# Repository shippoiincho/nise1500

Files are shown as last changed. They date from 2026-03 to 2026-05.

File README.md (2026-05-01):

# 偽 1500 for MZ-700

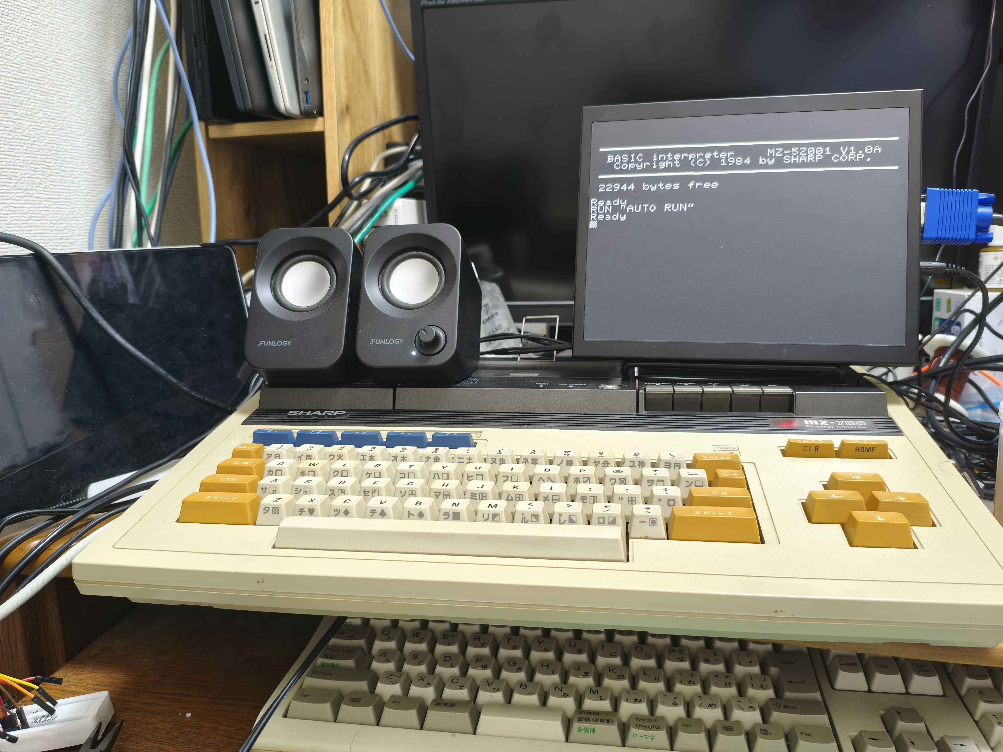
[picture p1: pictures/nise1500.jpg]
nise1500


## これはなに？

MZ-700 を MZ-1500 もどきにします。
本体の拡張コネクタに装着します。
映像は VGA コネクタから、音声は 3.5mm Jack から出力されます。
QuickDisk は読み込み専用でサポートされています。

偽 RAMFILE の以下の機能もありますが、フラシュサイズの関係で一部容量が削減されています。

- MZ-1R18 RAMFILE
- MZ-1R23 漢字 ROM
- MZ-1R24 辞書 ROM
- MZ-1R12 SRAM メモリ
- PIO-3034 EMM
- PCG-700

---
## 回路

board

Z80 Bus に直結するために、
ピンの多い RP2350B のボード(WeAct RP2350B Core Board)を使用します。
カートリッジスロットの信号を、単純に Raspberry Pi Pico2 に接続しただけです。
Pico2 が 5V 耐性なのを良いことに直結しています。

```
GP0-7:  D0-7
GP8-23: A0-15
GP24: EXINT
GP25: RESET
GP26: M1
GP28: MERQ
GP29: IORQ
GP30: WR
GP31: RD
GP32: EXWAIT
VBUS: 5V
GND: GND
```

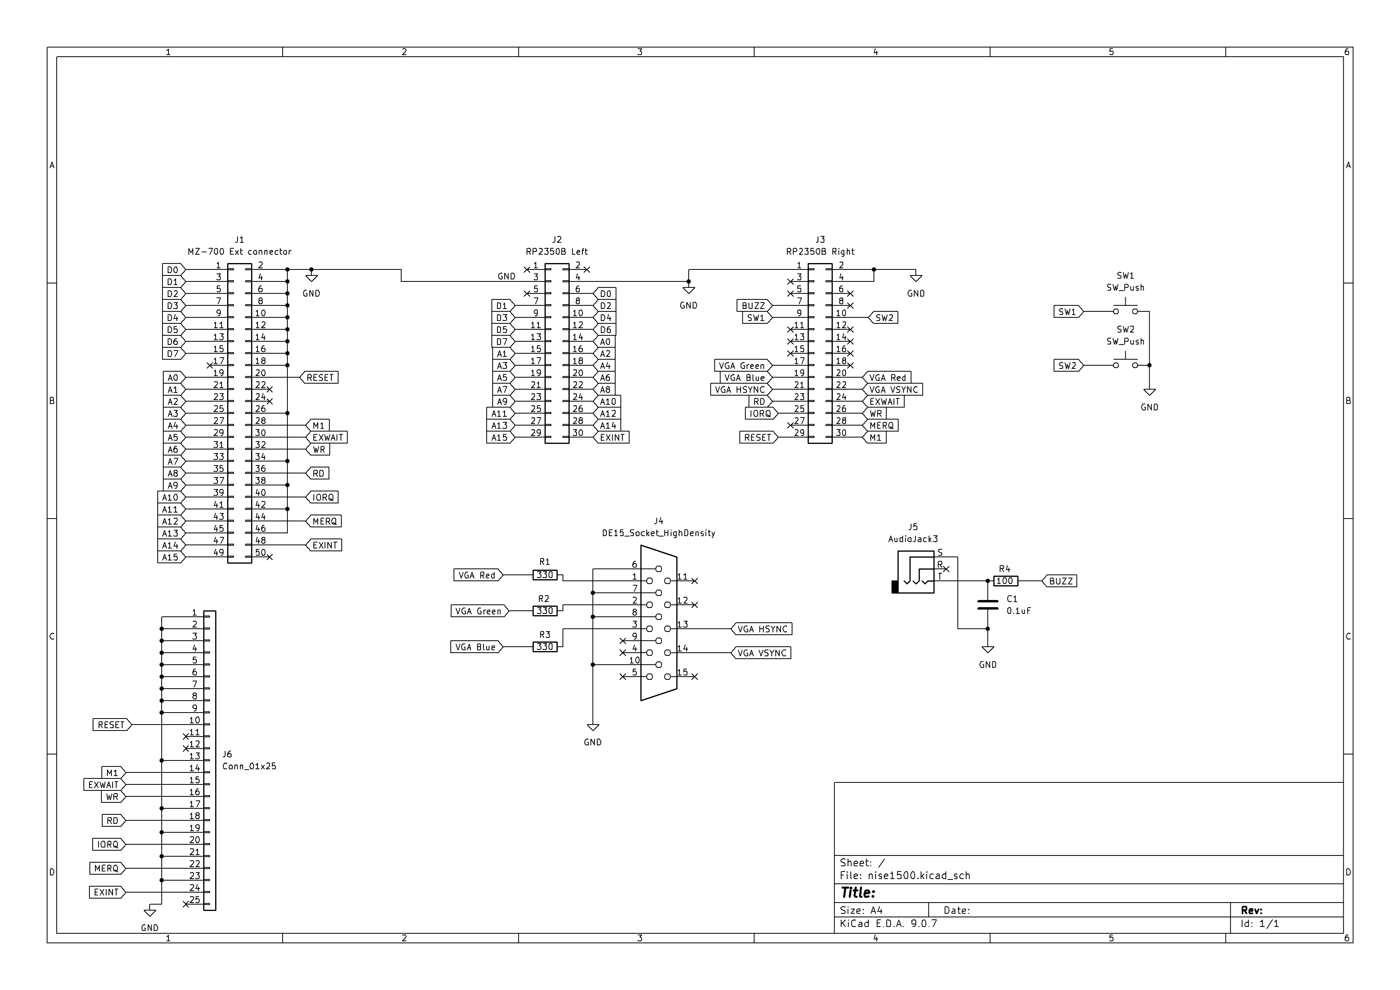
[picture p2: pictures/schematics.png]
Schematics


付属の基板データ `GERBER-nise1500.zip` を用いた場合、MZ-700 の背面コネクタに直結する形を想定しています。
延長ケーブルを使う際はコネクタの装着方向に注意してください。
3.5mm Jack は[ST-005-G](https://akizukidenshi.com/catalog/g/g102460/)を使っています。

MZ-700 の拡張コネクタには電源が出ていません。
別途 Pico の USB 端子などに電源を接続する必要があります。

---
## バイナリとか

`nise1500.uf2` をフラッシュに書き込んでください。
PCG書き込み時にウェイトが入るように調整していますが、環境によってはただしく動作しないことがあります。
BASIC 上で `CLS 2` を実行して正しく画面消去されるかどうか確認してください。

```
INIT "CRT:G"
PAINT [7]0,0
CLS 2
```

これで画面にゴミが残るようであれば、PCG ウェイトが正しく動作していません。

ソース上の `#define PCGWAIT` をコメントアウトすると PCG 書き込みのウェイトがなくなり安定動作しますが、
ソフトによっては速度が速すぎて不具合が生じることがあります。
`nise1500_nopcgwait.uf2` はウェイトオフで作成していますので、こちらを書き込んでください。

---
## 拡張ROM

MZ-1500 の拡張 ROM が必要です。実機から入手してください。

```
picotool.exe load -v -x ext.rom  -t bin -o 0x1001d000
```

---
## QD

QD のイメージ(QDF) ファイルは LittleFS 上に配置します。
LittleFS 領域は 8MiB なので、以下のように作成します。

```
mklittlefs -b 4096 -s 8388608 -c ./nise1500 nise1500.img
```

作った LittleFS イメージを Pico の Flash に書き込みます。

```
picotool.exe load -v -x nise1500.img -t bin -o 0x10800000
```

なお、QuickDisk は読み込み専用です。書き込みはできません。

LittleFS の取り扱いについては、詳しくは[こちらの記事](https://shippoiincho.github.io/posts/39/)を見てください。

QD ファイルの選択は SW1/SW2 を使います。
VGA 画面の一番下(26行目)に選択したファイル名が一定時間表示されます。

---
## MZ-1R18 RAMFILE

64KB の RAM FILE のエミュレーションをします。
BASIC から INIT "RAM:" などで使用することができます。

---
## MZ-1R23 漢字ROM

漢字ROM のエミュレートをします。
あらかじめ picotool などで漢字 ROM のデータを書き込んでおく必要があります。

```
picotool.exe load -v -x kanji.rom  -t bin -o 0x10020000
```

---
## MZ-1R24 辞書ROM

同じく辞書ROM のエミュレートをします。
あらかじめ picotool などで辞書 ROM のデータを書き込んでおく必要があります。

```
picotool.exe load -v -x dict.rom  -t bin -o 0x10040000
```

---
## MZ-1R12 SRAM メモリ

32KB の SRAM メモリのエミュレーションをします。
電源投入時は Checksum Error で止まるようにしています。

フラッシュとのやり取りは、I/O ポートの $BA,$BB を通して行えます。
内部的には 0-63 のバックアップスロットがあって、リード・ライトを制御できます。

$BA に出力するとその番号のスロットから SRAM に読み込みます。

```
OUT@ $BA,1
```

このあとリセットすると、SRAM から起動できます。

$BB に出力すると、SRAM の内容をその番号のスロットに書き込みます。

```
OUT@ $BB,2
```

なお、書き込み中は VGA 出力が停止します。

スロットに書き込みを行っていないデータは電源を切ると消滅します。

基本的な使い方は、モニタの ES コマンドでテープのソフトを SRAM に保存したのち、BASIC 上で上記コマンドで書き込みを行うことになるでしょう。

なお、エミュレータなどで作成したデータを記録することもできます。
アドレス 0x10080000 から 32KiB 単位でおいてください。
最初(0番)のデータは以下のように書き込みます。

```
picotool.exe load -v -x MZboot.rom  -t bin -o 0x10080000
```

起動できるデータの作成を PC 上でするには、
yanataka60さんの[MZ-1500SD 付属のツール 1Z-1R12_Header](https://github.com/yanataka60/MZ-1500_SD)
を使用すると便利です。

---
## PIO-3034 EMM

320KB の EMM をエミュレートします。
Hu-BASIC などで使用することができます。

こちらも I/O ポートの $BC,$BD で読み書きの制御が可能です。
偽 RAMFILE と違ってスロットは 0 - 15 しかありません。

$BC にスロット番号を出力すると EMM に読み込みます。
HuBASIC では以下のように操作します。

```
OUT &HBC,1
```

$BD にスロット番号を出力すると、EMM の内容をフラッシュに書き込みます。

```
OUT &HBD,2
```

なお、書き込み中は VGA 出力が停止します。

フラッシュに書き込みを行っていないデータは電源を切ると消滅します。

---
## PCG-700

VGA 出力に PCG-700 のエミュレーションをします。
本体出力との同期をとっていませんので、ソフトウェアによっては正しく描画されないことがあります。

本来 PCG-700 は、バンク切り替えに関係なく反応しますが、
MZ-1500 用ソフトの動作に支障があるために、VRAM 選択時にのみ動作します。

なお、あらかじめ本体の CG-ROM の内容をフラッシュに書き込んでおく必要があります。

```
picotool.exe load -v -x font.rom  -t bin -o 0x1001f000
```

---
## 制限事項

- ~~MZ-700 に存在しない PCG-RAM のアクセス時にウェイトが入りません。いくつかのソフトで MZ-1500 実機より早くなります~~
- QD は読み込み専用です
- ソフトによっては本体のスピーカーからノイズが発生します。本体のスピーカーの音量調節で対応してください。
- SRAM および EMM データを Flash に書き込む際には VGA 出力が乱れます
- **Flash 書き込み時に QuickDisk、漢字 ROM および辞書 ROM にアクセスすると、ボードの機能が停止します。絶対に行わないでください。**

---
## 使用ライブラリなど

- [LittleFS](https://github.com/littlefs-project/littlefs)
- [VGA ライブラリ(一部改変)](https://github.com/vha3/Hunter-Adams-RP2040-Demos/tree/master/VGA_Graphics)

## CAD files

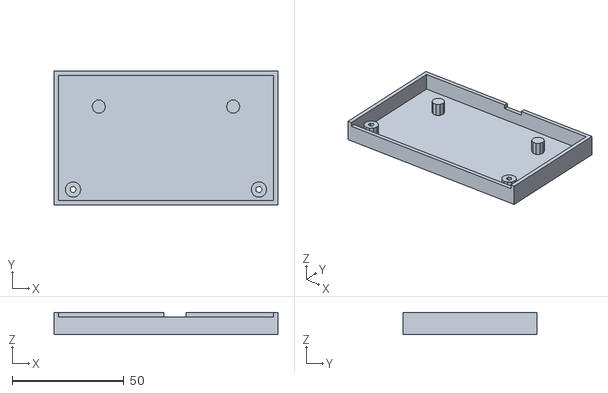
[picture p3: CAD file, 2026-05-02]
case/nise1500case_bottom.stl
100.0 x 60.0 x 10.0

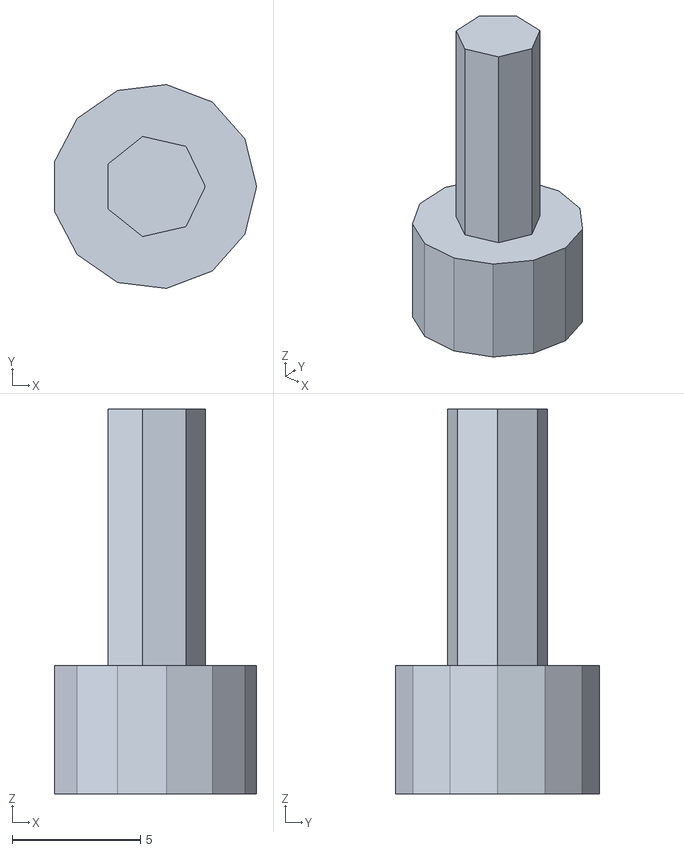
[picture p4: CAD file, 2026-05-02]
case/nise1500case_button.stl
7.88 x 7.94 x 15.0

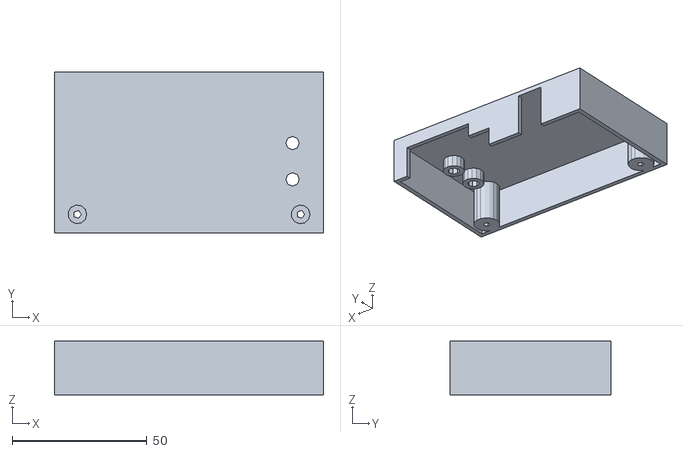
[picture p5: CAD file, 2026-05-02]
case/nise1500case_upper.stl
100.0 x 60.0 x 20.0

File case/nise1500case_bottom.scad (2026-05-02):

// Bottom Outer

difference() {

translate([-50,-30,-10]) {    
cube([100,60,10]);
}


translate([-48,-28,-8]) {  
cube([96,56,8]);
}

translate([-48,-30,-2]) {       
cube([96,56,2]);
    
}

// LINE OUT

translate([-1,25,-2]) {

cube([10,6,2]);

}


translate([-41.5,-23,-10]) {
    
cylinder(6,1.5,1.5);

}

translate([+41.5,-23,-10]) {
        
cylinder(6,1.5,1.5);

}

}


// Bottom Hole 1

translate([-41.5,-23,-8]) {

difference() {
    
cylinder(6,3.5,3.5);    
    
cylinder(6,1.5,1.5);

}
   
}

// Botom Hole 2

translate([+41.5,-23,-8]) {

difference() {
    
cylinder(6,3.5,3.5);    
    
cylinder(6,1.5,1.5);

}
   
}

// Support

translate([-30,14,-8]) {
    

cylinder(6,3,3);

}

translate([30,14,-8]) {
    

cylinder(6,3,3);

}

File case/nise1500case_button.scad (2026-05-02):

cylinder(15,2,2);
cylinder(5,4,4);

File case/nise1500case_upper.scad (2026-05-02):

// Bottom Outer

difference() {

translate([-50,-30,0]) {    
cube([100,60,20]);
}


translate([-48,-28,0]) {  
cube([96,56,18]);
}

translate([-48,-30,-2]) {       
cube([96,56,2]);
    
}

// VGA

translate([10,25,0]) {

cube([33,10,14]);

}

// LINE OUT

translate([-1,25,0]) {

cube([18,6,8]);

}

// USB 

translate([-29,25,0]) {

cube([12,10,18]);

}

// Button Hole

translate([38.5,3.5,18]) {

cylinder(2,2.5,2.5); 

}

translate([38.5,-10,18]) {

cylinder(2,2.5,2.5); 

}


// Mount Hole

translate([-41.5,-23,18]) {
    
cylinder(2,3.5,3.5);    
       
}

translate([41.5,-23,18]) {
    
cylinder(2,3.5,3.5);    
       
}


}


// Upper Hole 1

translate([-41.5,-23,0]) {

difference() {
    
cylinder(4,3.5,3.5);    
    
cylinder(4,1.5,1.5);

}
   
}

translate([-41.5,-23,0]) {

difference() {
    
cylinder(18,5.5,5.5);    
    
cylinder(18,3.5,3.5);

}
   
}



// Upper Hole 2

translate([+41.5,-23,0]) {

difference() {
    
cylinder(4,3.5,3.5);    
    
cylinder(4,1.5,1.5);

}
   
}

translate([+41.5,-23,0]) {

difference() {
    
cylinder(18,5.5,5.5);    
    
cylinder(18,3.5,3.5);

}
   
}

// Button hole

translate([38.5,3.5,13]) {

difference() {

cylinder(5,4.5,4.5); 
    
cylinder(5,2.5,2.5);     
}

}

translate([38.5,-10,13]) {

difference() {

cylinder(5,4.5,4.5);    

cylinder(5,2.5,2.5); 

}

}

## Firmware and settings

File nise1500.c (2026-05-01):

//  MZ-1500 Emulator for MZ-700
//
//  MZ-1R12: RAM Memory
//  MZ-1R18: RAMFILE
//  MZ-1R23: Kanji ROM
//  MZ-1R24: Jisho ROM
//  PIO-3034: EMM

//  MZ-700 extention slot
//  GP0-7:  D0-7
//  GP8-23: A0-15
//  GP24: EXINT
//  GP25: RESET -> Interrupt
//  GP26: M1
//  GP28: MERQ
//  GP29: IORQ
//  GP30: WR
//  GP31: RD
//  GP32: EXWAIT

#include <stdio.h>
#include <stdlib.h>
#include <string.h>

#include "pico/stdlib.h"
#include "pico/multicore.h"
#include "pico/sync.h"
#include "hardware/pio.h"
#include "hardware/clocks.h"
#include "hardware/timer.h"
#include "hardware/uart.h"
#include "hardware/flash.h"
#include "hardware/sync.h"
#include "hardware/vreg.h"
#include "hardware/pwm.h"

#include "vga16_graphics.h"

#include "misc.h"
#include "lfs.h"

#define RESET_PIN 25

// RAM configuration
// MZ-1R18: 64KiB
// MZ-1R12: 32KiB
// EMM:    320KiB

uint8_t __attribute__  ((aligned(sizeof(unsigned char *)*4096))) mz1r12[0x8000];
uint8_t __attribute__  ((aligned(sizeof(unsigned char *)*4096))) mz1r18[0x10000];
uint8_t __attribute__  ((aligned(sizeof(unsigned char *)*4096))) emm[0x50000];

// PCG emulation (36KiB)
// VRAM  4KiB
// CGRAM 4Kib
// PCG   24KiB

uint8_t vram[0x1000];
uint8_t cgram[0x1000];
uint8_t pcg[0x2000 * 3];
uint8_t pcg700[0x800];
uint8_t memioport[0x10];

volatile uint8_t vram_enabled;
volatile uint8_t pcg_enabled;

uint8_t extram[0x1800];

#define PCGWAIT             // Enable WAIT for PCG-RAM write access
#define PSGWAIT             // Enable WAIT for PSG write

volatile uint32_t merq_count=0;

#define MAXROMPAGE 64       // =  32KiB * 64 pages = 2048KiB
#define MAXEMMPAGE 16       // = 320KiB * 16 pages = 5120KiB

volatile uint8_t rompage=0;  // Page No of MZ-1R12 (64KiB/page)
volatile uint8_t emmpage=0;  // Page No of EMM (320KiB/page)

volatile uint32_t kanjiptr=0;
volatile uint32_t dictptr=0;
volatile uint32_t kanjictl=0;
volatile uint32_t mz1r18ptr=0;
volatile uint32_t mz1r12ptr=0;
volatile uint32_t emmptr=0;
volatile uint32_t flash_command=0;
volatile uint32_t pcg700_ptr=0;

// ROM configuration
// WeACT RP2350B with 16MiB Flash
// EXT ROM          8KiB   @ 0x1001d000
// FONT ROM         4KiB   @ 0x1001f000
// Kanji ROM        128KiB @ 0x10020000
// Jisho ROM        256KiB @ 0x10040000
// Data for 1R12    32KiB  * 64 = 2048KiB   @ 0x10080000
// Data for EMM     320KiB * 16 = 5120KiB   @ 0x10280000
// LittleFS         8MiB  @ 0x10800000

#define ROMBASE 0x10080000u

uint8_t *extrom=(uint8_t *)(ROMBASE-0x63000);
uint8_t *fontrom=(uint8_t *)(ROMBASE-0x61000);
uint8_t *kanjirom=(uint8_t *)(ROMBASE-0x60000);
uint8_t *jishorom=(uint8_t *)(ROMBASE-0x40000);
uint8_t *romslots=(uint8_t *)(ROMBASE);
uint8_t *emmslots=(uint8_t *)(ROMBASE+(0x8000*MAXROMPAGE));

// Define the flash sizes
// This is setup to read a block of the flash from the end 
#define BLOCK_SIZE_BYTES (FLASH_SECTOR_SIZE)
#define HW_FLASH_STORAGE_BYTES  (8 * 1024 * 1024)
#define HW_FLASH_STORAGE_BASE   (PICO_FLASH_SIZE_BYTES - HW_FLASH_STORAGE_BYTES) 

lfs_t lfs;
lfs_file_t lfs_file;

// VGA Output
uint8_t scandata[320];
extern unsigned char vga_data_array[];
volatile uint32_t video_hsync,video_vsync,scanline,vsync_scanline;
volatile uint8_t pcg_control;
volatile uint8_t pcg700_control,pcg700_data;
uint8_t pallet[8];

uint8_t colors[16]; // DUMMY
uint16_t status[40]; // Status line (26th line)

// QD
volatile uint8_t qd_status=0;
uint8_t qd_filename[65];
lfs_file_t qd_drive;
uint8_t qd_motor=0;
volatile uint8_t qd_data;
uint32_t qd_ptr=0;
uint32_t qd_blocksize=0;
uint32_t qd_sync=0;
uint32_t qd_type=0;
uint32_t qd_stage=0;
uint8_t qd_numblocks=0;
uint32_t qd_count;
volatile uint8_t qd_data_ready=0;
volatile uint32_t qd_data_request;

uint8_t qd_header[]={0xa5,0x00,0x00,0x00,0x16};

uint32_t qdimage_numfiles;
uint32_t qdimage_selected=0;
uint32_t qdimage_display_count=0;

#define QDIMAGE_TIME   600

// BEEP & PSG

uint32_t pwm_slice_num;
volatile uint32_t sound_tick=0;

#define PSG_NUMBERS 2

uint16_t psg_register[8 * PSG_NUMBERS];
uint32_t psg_osc_interval[3 * PSG_NUMBERS];
uint32_t psg_osc_counter[3 * PSG_NUMBERS];

uint32_t psg_noise_interval[PSG_NUMBERS];
uint32_t psg_noise_counter[PSG_NUMBERS];
uint8_t psg_noise_output[PSG_NUMBERS];
uint32_t psg_noise_seed[PSG_NUMBERS];
uint32_t psg_freq_write[PSG_NUMBERS];
// uint32_t psg_envelope_interval[PSG_NUMBERS];
// uint32_t psg_envelope_counter[PSG_NUMBERS];
//uint32_t psg_master_clock = PSG_CLOCK2;
//uint32_t psg_master_clock = (3579545/2);
uint32_t psg_master_clock = 3579545;
uint16_t psg_master_volume = 0;

// TESUTO
uint32_t psg_note_count;

uint16_t psg_volume[] = { 0xFF,0xCB,0xA1,0x80,0x66,0x51,0x40,0x33,0x28,0x20,0x1A,0x14,0x10,0x0D,0x0A,0x00};

//#define SAMPLING_FREQ 48000
#define SAMPLING_FREQ 31500
//#define SAMPLING_FREQ 22050
#define TIME_UNIT 100000000                           // Oscillator calculation resolution = 10nsec
#define SAMPLING_INTERVAL (TIME_UNIT/SAMPLING_FREQ) 

#define I8253CLOCK 894000 // NTSC
//#define I8253CLOCK 1108000 // PAL

volatile uint8_t sioa[8],siob[8];
volatile uint8_t sioa_access,siob_access;

volatile uint8_t pioa[4],piob[4];
volatile uint32_t pioa_enable_irq=0;
volatile uint32_t piob_enable_irq=1;
uint32_t pioa_next_mask,pioa_next_iocontrol;
uint32_t piob_next_mask,piob_next_iocontrol;
uint32_t pio_irq_processing=0;
volatile uint8_t pioa_data;
//
uint8_t pioa_int_debug=0;

volatile uint8_t i8253[3];
volatile uint8_t i8253_access[3];
volatile uint16_t i8253_preload[3];
volatile uint16_t i8253_counter[3];
volatile uint8_t i8253_pending[3];
volatile uint16_t i8253_latch[3];
volatile uint32_t i8253_latch_flag=0;
volatile uint32_t i8253_enable_irq=0;
volatile uint32_t beep_flag=0;
volatile uint32_t beep_mute=0;

// Button status

uint32_t button1=0;
uint32_t button2=0;
volatile uint32_t button1_pressed=0;
volatile uint32_t button2_pressed=0;
volatile uint32_t button1_long=0;
volatile uint32_t button2_long=0;
#define BUTTON_MIN 10
#define BUTTON_LONG 300

//uint8_t __attribute__  ((aligned(sizeof(unsigned char *)*4096))) flash_buffer[4096];

void __not_in_flash_func(mzscan)(uint8_t scan);
void __not_in_flash_func(statusscan)(uint8_t scan);
bool __not_in_flash_func(sound_handler)(void);

// *REAL* H-Sync for emulation
void __not_in_flash_func(hsync_handler)(void) {

    uint32_t vramindex;
    uint32_t tmsscan;
    uint8_t bgcolor;

    pio_interrupt_clear(pio0, 0);

        sound_handler();

    if((scanline!=0)&&(gpio_get(VSYNC)==0)) { // VSYNC
        scanline=0;
        video_vsync=1;

        // check button

        if(gpio_get(45)!=0) {
            button1++;
        } else {
            if(button1>BUTTON_LONG) {
                button1_long=1;
            } else if (button1>BUTTON_MIN) {
                button1_pressed=1;
            }
            button1=0;
        }

        if(gpio_get(46)!=0) {
           button2++;
        } else {
            if(button2>BUTTON_LONG) {
                button2_long=1;
            } else if (button2>BUTTON_MIN) {
                button2_pressed=1;
            }
            button2=0;
        }

        if(qdimage_display_count) {
            qdimage_display_count--;
            if(qdimage_display_count==0) {
                memset(status,0,80);
            }
        }

    } else {
        scanline++;
    }

    if((scanline%2)==0) {
        video_hsync=1;

        // VDP Draw on HSYNC

        // VGA Active starts scanline 35
        //          Active scanline 78(0) to 477(199)

        if((scanline>=73)&&(scanline<=(472+16))) {
//        if((scanline>=81)&&(scanline<=480)) {

            tmsscan=(scanline-73)/2;
//            tmsscan=(scanline-81)/2;
            vramindex=(tmsscan%4)*320;

            if(tmsscan<200) {
                mzscan(tmsscan);
            } else {
                statusscan(tmsscan-200);
            }



            for(int j=0;j<320;j++) {
                vga_data_array[vramindex+j]=scandata[j];
            }           
        }

    }

    // run i8253 channel 1/2
    // Channel 1 15.75kHz (mode 2)
    // Channel 2 (mode 0)

        if((i8253_access[1]<2)&&(i8253_preload[1]!=0)) {
            if(i8253_counter[1]>1) {
                i8253_counter[1]--;
                if (i8253_counter[1]==1) {
                    if((i8253_access[2]<2)&&(i8253_preload[2]!=0)){
                        if(i8253_pending[2]) {
                            i8253_pending[2]=0;
                        } else {
                            if (i8253_counter[2]>1) {
                                i8253_counter[2]--;
                                
                                pioa_data&=0xd0;

                            } else {
//                            i8253_counter[2]=i8253_preload[2];
                              i8253_counter[2]=65535;
                                // Timer Interrupt
                                // Check mask
                                if(memioport[2]&0x4) { 
                                    i8253_enable_irq=2;
                                }
                                if((pioa[2]&0x80)&&((pioa[3]&0x20)==0)) { 
                                    pioa_enable_irq=1;

                                    pioa_data|=0x20;
//                                    ioport[0xfe]|=0x20;
                                }
                            }
                        } 
                    }
                }
            } else {
                i8253_counter[1]=i8253_preload[1];
            }
        }

//        sound_handler();

    return;

}

// BEEP and PSG emulation
//bool __not_in_flash_func(sound_handler)(struct repeating_timer *t) {
bool __not_in_flash_func(sound_handler)(void) {

    uint16_t timer_diffs;
    uint32_t pon_count;
    uint16_t master_volume;
    uint32_t beep_on,beep_volume;
    uint8_t tone_output[3 * PSG_NUMBERS], noise_output[3 * PSG_NUMBERS];

    pwm_set_chan_level(pwm_slice_num,PWM_CHAN_B,psg_master_volume);

    // BEEP
    // i8253 timer 0

    beep_on=0;

    if(memioport[8]&1) {  // i8253 GATE#0 enable

        timer_diffs= I8253CLOCK / SAMPLING_FREQ;

        if(timer_diffs<i8253_counter[0]){
            i8253_counter[0]-=timer_diffs;

            if(memioport[2]&1) {  // Beep flag

                beep_on=1;

                if((i8253[0]&0xe)==6) {  // Mode 3

                    if(i8253_counter[0]>(i8253_preload[0]/2)) {
                        beep_volume=255;
                    } else {
                        beep_volume=0;
                    }
                } else if((i8253[0]&0xe)==0){ // mode 0                    
                    beep_volume=0;
                } else if((i8253[0]&0xe)==0xa){ // mode 5                    
                    beep_volume=255;
                }
            } else {
                beep_on=0;
            }

            pioa_data&=0xe0;

        } else {
            i8253_counter[0]=i8253_counter[0]+(i8253_preload[0]-timer_diffs);

            // interrupt via Z80PIO

                if((pioa[2]&0x80)&&((pioa[3]&0x10)==0)) {
                        pioa_enable_irq=1;
                        pioa_data|=0x10;
//                        ioport[0xfe]|=0x10;

                }

        }
    } else {
        if(memioport[2]&1) {
            beep_on=1; 
            beep_volume=255;
        } else {
            beep_on=0;
            beep_volume=0;
        }
    }

    // PSG

    // Run Noise generator

    for (int i = 0; i < PSG_NUMBERS; i++) {

        psg_noise_counter[i] += SAMPLING_INTERVAL;
        if (psg_noise_counter[i] > psg_noise_interval[i]) {
            psg_noise_seed[i] = (psg_noise_seed[i] >> 1)
                    | (((psg_noise_seed[i] << 14) ^ (psg_noise_seed[i] << 16))
                            & 0x10000);
            psg_noise_output[i] = psg_noise_seed[i] & 1;
            psg_noise_counter[i] -= psg_noise_interval[i];
        }

    }

    // Run Oscillator

    for (int i = 0; i < 3 * PSG_NUMBERS; i++) {
        pon_count = psg_osc_counter[i] += SAMPLING_INTERVAL;
        if (pon_count < (psg_osc_interval[i] / 2)) {
//            tone_output[i] = psg_tone_on[i];
            tone_output[i] = 1;
        } else if (pon_count > psg_osc_interval[i]) {
            psg_osc_counter[i] -= psg_osc_interval[i];
//            tone_output[i] = psg_tone_on[i];
            tone_output[i] = 1;
        } else {
            tone_output[i] = 0;
        }
    }

    // Mixer

    master_volume = 0;
    psg_note_count=0;

    for (int i = 0; i < PSG_NUMBERS; i++) {
        for (int j = 0; j < 3; j++) {
            if(tone_output[j+i*3]) {
                master_volume+=psg_volume[psg_register[j*2+i*8+1]];
//                master_volume+=psg_volume[32];
            } 
        }
        if(psg_noise_output[i]) {
            master_volume+=psg_volume[psg_register[7+i*8]];
        }
    }

    // count enable channels

    for (int i = 0; i < PSG_NUMBERS; i++) {
        for (int j = 0; j < 4; j++) {
            if(psg_register[j*2+i*8+1]!=0xf) {
                    psg_note_count++;
            }            
        }
    }

    if(beep_on) {
        psg_note_count++;
        master_volume+=beep_volume;
    }

//    psg_master_volume = master_volume / (3 * PSG_NUMBERS);
    psg_master_volume = master_volume / psg_note_count;


    return true;
}

// PSG virtual registers
// 0: CH0 Freq
// 1: CH0 Volume
// 6: Noise Freq
// 7: Noise Volume
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
int main() {

    uint32_t menuprint=0;
    uint32_t filelist=0;
    uint32_t subcpu_wait;
    uint32_t rampacno;
    uint32_t pacpage;

    static uint32_t hsync_wait,vsync_wait;

    vreg_set_voltage(VREG_VOLTAGE_1_20);  // for overclock to 300MHz
    set_sys_clock_khz(300000 ,true);

    initVGA();

    multicore_launch_core1(main_core1);

    init_emulator();

    irq_set_exclusive_handler (PIO0_IRQ_0, hsync_handler);
    irq_set_enabled(PIO0_IRQ_0, true);
    pio_set_irq0_source_enabled (pio0, pis_interrupt0 , true);

    // Set RESET# interrupt

//    gpio_set_irq_enabled_with_callback(RESET_PIN,GPIO_IRQ_EDGE_FALL,true,z80reset);
    gpio_set_irq_enabled_with_callback(RESET_PIN,GPIO_IRQ_EDGE_RISE,true,z80reset);


    // Mount LittleFS (8MiB)

    // mount littlefs
    if(lfs_mount(&lfs,&PICO_FLASH_CFG)!=0) {
       // format
       lfs_format(&lfs,&PICO_FLASH_CFG);
       lfs_mount(&lfs,&PICO_FLASH_CFG);
   }

   // Initialize buttons

   gpio_init(45);
   gpio_init(46);
   gpio_set_dir(45,false);
   gpio_set_dir(46,false);
   gpio_set_pulls(45,true,false);
   gpio_set_pulls(46,true,false);

   // BEEP

    gpio_set_function(47,GPIO_FUNC_PWM);
    pwm_slice_num = pwm_gpio_to_slice_num(47);

    pwm_set_wrap(pwm_slice_num, 256);
    pwm_set_chan_level(pwm_slice_num, PWM_CHAN_B, 0);
    pwm_set_enabled(pwm_slice_num, true);

    qdimage_numfiles=qd_count_files();
    qdimage_selected=0;

    while(1) {

        if(flash_command!=0) {

            switch(flash_command&0xf0000000) {

                case 0x10000000:  // SRAM load
                    memcpy(mz1r12,romslots+((flash_command&0x3f))*0x8000u,0x8000);
                    break;

                case 0x20000000:  // SRAM Save

                    for(uint32_t i=0;i<0x8000;i+=4096) {
                    uint32_t ints = save_and_disable_interrupts();
//                    multicore_lockout_start_blocking();     // pause another core
                    flash_range_erase(i+0x80000u+((flash_command&0x3f))*0x8000u, 4096);  
//                    multicore_lockout_end_blocking();
                    restore_interrupts(ints);
                    }

                    for(uint32_t i=0;i<0x8000;i+=4096) {
                    uint32_t ints = save_and_disable_interrupts();
//                    multicore_lockout_start_blocking();     // pause another core
                    flash_range_program(i+0x80000u+((flash_command&0x3f))*0x8000u, (const uint8_t *)(mz1r12+i), 4096);
//                    multicore_lockout_end_blocking();
                    restore_interrupts(ints);
                    }

                    break;

                case 0x30000000:  // EMM load
                    memcpy(emm,emmslots+(flash_command&0xf)*0x50000u,0x50000);
                    break;                    

                case 0x40000000:  // EMM Save

                    for(uint32_t i=0;i<0x50000;i+=4096) {
                    uint32_t ints = save_and_disable_interrupts();
//                    multicore_lockout_start_blocking();     // pause another core
                    flash_range_erase(i+0x280000u+(flash_command&0xf)*0x50000u, 4096);
//                    multicore_lockout_end_blocking();
                    restore_interrupts(ints);
                    }

                    for(uint32_t i=0;i<0x50000;i+=4096) {
                    uint32_t ints = save_and_disable_interrupts();
//                    multicore_lockout_start_blocking();     // pause another core
                    flash_range_program(i+0x280000u+(flash_command&0xf)*0x50000u, (const uint8_t *)(emm+i), 4096);
//                    multicore_lockout_end_blocking();
                    restore_interrupts(ints);
                    }

                case 0x50000000:  // PSG1
                    psg_write(0,flash_command&0xff);
                    break;

                case 0x60000000:  // PSG2
                    psg_write(1,flash_command&0xff);
                    break;

                case 0x70000000:  // PSG1+2
                    psg_write(0,flash_command&0xff);
                    psg_write(1,flash_command&0xff);
                    break;

                case 0x80000000:  // QD ON
                    if(qd_status) {
                        lfs_file_seek(&lfs,&qd_drive,0,LFS_SEEK_SET);
                        qd_data_request=1;

                    }


                    break;

                case 0x90000000:  // QD Read
                    break;

                case 0xa0000000:  // QD Write
                    break;                    


                    break;  

            }
            flash_command=0;

        }

        // EXINT

        if(pioa_enable_irq) {
            gpio_put(24,false);
        }

        // if(qd_motor) {
        //     status[39]=0x6b;
        // } else {
        //     status[39]=0;
        // }

        // QD read

        if((qd_motor)&&(qd_data_request)) {
            qd_data=qd_read();
            qd_data_request=0;
            qd_data_ready=1;
        }

        // UI 

        if(button1_pressed) {

            if(qd_status) {
                lfs_file_close(&lfs,&qd_drive);
                qdimage_selected++;
                if(qdimage_selected>=qdimage_numfiles) {
                    qdimage_selected=0;
                }                
            }

            qd_select_image(qdimage_selected);
            draw_filename();

            lfs_file_open(&lfs,&qd_drive,qd_filename,LFS_O_RDONLY);

            qd_check();
            qd_status=1;
            button1_pressed=0;
            qdimage_display_count=QDIMAGE_TIME;

        }

        if(button2_pressed) {

            if(qd_status) {
                lfs_file_close(&lfs,&qd_drive);
                if(qdimage_selected==0) {
                    qdimage_selected=qdimage_numfiles;
                }
                qdimage_selected--;                                  
            }

            qd_select_image(qdimage_selected);
            draw_filename();

            lfs_file_open(&lfs,&qd_drive,qd_filename,LFS_O_RDONLY);

            qd_check();
            qd_status=1;
            button2_pressed=0;
            qdimage_display_count=QDIMAGE_TIME;

        }

        if(button1_long) {
            if(qd_status) {
                lfs_file_close(&lfs,&qd_drive);
                qd_status=0;
                button1_long=0;
            }
            memset(status,0,80);
        }

    }
}
